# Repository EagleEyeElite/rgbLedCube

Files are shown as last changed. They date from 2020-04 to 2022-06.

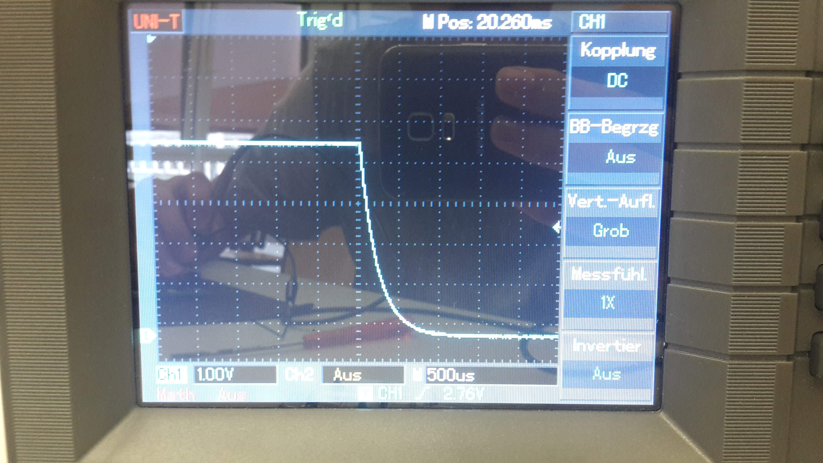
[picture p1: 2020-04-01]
board/notes/20180619_152910.jpg

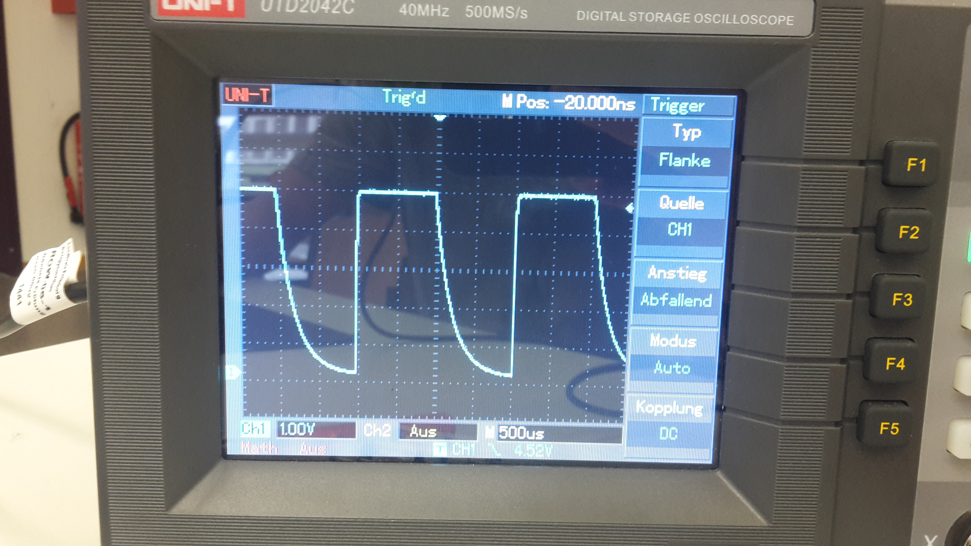
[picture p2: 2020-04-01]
board/notes/20180619_154544.jpg

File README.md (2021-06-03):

# 3x3x3 RGB LED Cube

## video
Led Cube (https://www.youtube.com/watch?v=q-ZB6mgsY2I "LED Cube") \
click image to open video

## board git conf:
[git setup](https://jnavila.github.io/plotkicadsch/) \
[example](https://github.com/John-Nagle/ttyloopdriver)

## programmer examples
```
Arduino: get terminal: avrdude -c stk500v1 -b 19200 -P /dev/ttyACM0 -p atmega1284p -t
Programmer: avrdude -c stk500 -b 115200 -P /dev/ttyACM0 -p atmega1284p -t
get all available ports: ls -l /dev/ttyACM*
```

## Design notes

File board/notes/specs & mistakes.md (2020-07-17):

Specs:
- mosfet: needs 1ms to turn off (from 5V to 0) (no load), switches back on instantly (no load)
 - but: switches instantly off aswell once there is a load -> no ghosting
- all TLC data lines switch instantly, only very small impacts on other lines
- 5V: on last TLC 5V pin, 0.25V ripple -> 5% power ripple, great for TLC
- no ripple on GND pin

Blank (on TLC) 1µS to switch on, switches off immediately
   -> (on µ-C) 1µS to switch off, switches on immediately
   -> delay due transistor inversion
   -> options: remove/short transitor, mosfets provide enough protection
	-replace R2 with 1k

mistakes:
    - TLC blank inverter (obsulete)
    - no debounce capazitor for switches
    - log instead of linear pot
    - too big capacitors (1000µF)
    - 22pf capacitor for 20 mhz crystal seems to break it
    - no usart serial port for debugging
    - n-channel mosfet would be better
    - no readout for TLC error register (useful for debugging)
    - dedicated reset button, button that triggers software reset would be better

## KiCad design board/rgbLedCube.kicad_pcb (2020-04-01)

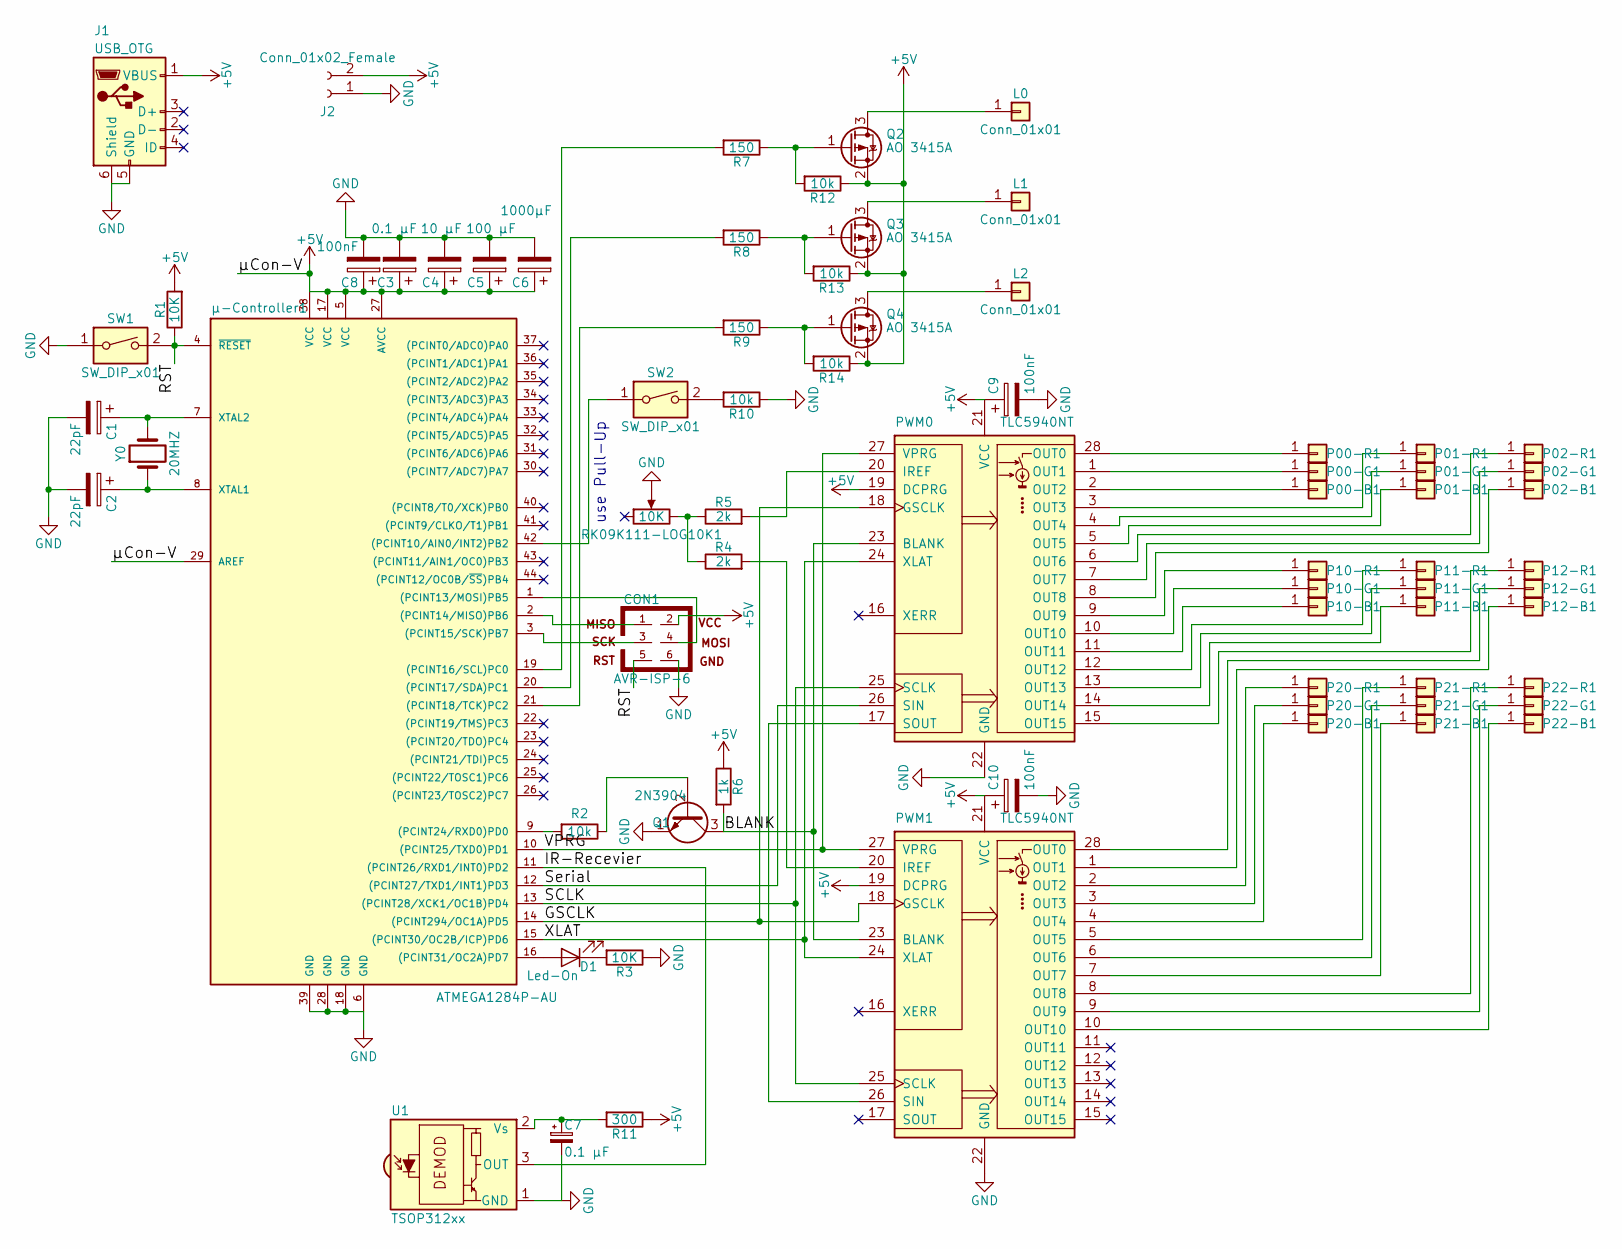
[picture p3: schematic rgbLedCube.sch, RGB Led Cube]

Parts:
C1, C2: 22pF; C_0603_HandSoldering
C3, C7: 0.1 µF; C_0603_HandSoldering
C4: 10 µF; CP_Elec_5x5.3
C5: 100 µF; CP_Elec_5x5.8
C6: 1000µF; CP_Elec_10x10.5
C8, C9, C10: 100nF; C_0603_HandSoldering
CON1: AVR-ISP-6; Pin_Header_Angled_2x03_Pitch2.54mm
D1: Led-On; LED_0603_HandSoldering
J1: USB_OTG; USB_Micro_Conn_Reichelt_Version_2
J2: Conn_01x02_Female; Pin_Header_Angled_1x02_Pitch2.54mm
L0, L1, L2: Conn_01x01; Pin_Header_Straight_1x01_Pitch2.54mm
P00-B1, P00-G1, P00-R1, P01-B1, P01-G1, P01-R1, P02-B1, P02-G1, P02-R1, P10-B1, P10-G1, P10-R1, P11-B1, P11-G1, P11-R1, P12-B1, P12-G1, P12-R1, P20-B1, P20-G1, P20-R1, P21-B1, P21-G1, P21-R1, P22-B1, P22-G1, P22-R1: Conn_01x01; Pin_Header_Straight_1x01_Pitch2.54mm
PWM0, PWM1: TLC5940NT; DIP-28_W7.62mm
Q1: 2N3904; TO-92_Molded_Narrow
Q2, Q3, Q4: AO 3415A; SOT-23
R1, R3: 10K; R_0805_HandSoldering
R2, R10, R12, R13, R14: 10k; R_0805_HandSoldering
R4, R5: 2k; R_0805_HandSoldering
R6: 1k; R_0805_HandSoldering
R7, R8, R9: 150; R_0805_HandSoldering
R11: 300; R_0805_HandSoldering
RK09K111-LOG10K1: 10K; Potentiometer-Alps
SW1, SW2: SW_DIP_x01; SW_Tactile_SPST_Angled_PTS645Vx83-2LFS
U1: TSOP312xx; IRReceiver_Vishay_CAST-3pin
Y0: 20MHZ; Crystal_SMD_HC49-SD
µ-Controller1: ATMEGA1284P-AU; TQFP-44_10x10mm_Pitch0.8mm

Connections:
+5V: C3.1, C4.1, C5.1, C6.1, C8.1, C9.1, C10.1, CON1.2, J1.1 (VBUS), J2.2, PWM0.19 (DCPRG), PWM0.21 (VCC), PWM1.19 (DCPRG), PWM1.21 (VCC), Q2.2 (S), Q3.2 (S), Q4.2 (S), R1.2, R6.1, R11.1, R12.1, R13.1, R14.1, µ-Controller1.5 (VCC), µ-Controller1.17 (VCC), µ-Controller1.27 (AVCC), µ-Controller1.29 (AREF), µ-Controller1.38 (VCC)
/BLANK: PWM0.23 (BLANK), PWM1.23 (BLANK), Q1.3 (C), R6.2
/GSCLK: PWM0.18 (GSCLK), PWM1.18 (GSCLK), µ-Controller1.14 ((PCINT294/OC1A)PD5)
/IR-Recevier: U1.3 (OUT), µ-Controller1.11 ((PCINT26/RXD1/INT0)PD2)
/RST: CON1.5, R1.1, SW1.2, µ-Controller1.4 (~RESET)
/SCLK: PWM0.25 (SCLK), PWM1.25 (SCLK), µ-Controller1.13 ((PCINT28/XCK1/OC1B)PD4)
/Serial: PWM0.26 (SIN), µ-Controller1.12 ((PCINT27/TXD1/INT1)PD3)
/VPRG: PWM0.27 (VPRG), PWM1.27 (VPRG), µ-Controller1.10 ((PCINT25/TXD0)PD1)
/XLAT: PWM0.24 (XLAT), PWM1.24 (XLAT), µ-Controller1.15 ((PCINT30/OC2B/ICP)PD6)
GND: C1.2, C2.2, C3.2, C4.2, C5.2, C6.2, C7.2, C8.2, C9.2, C10.2, CON1.6, J1.5 (GND), J1.6 (Shield), J2.1, PWM0.22 (GND), PWM1.22 (GND), Q1.1 (E), R3.1, R10.1, RK09K111-LOG10K1.2, SW1.1, U1.1 (GND), µ-Controller1.6 (GND), µ-Controller1.18 (GND), µ-Controller1.28 (GND), µ-Controller1.39 (GND)
unnamed: C1.1, Y0.2, µ-Controller1.7 (XTAL2)
unnamed: C2.1, Y0.1, µ-Controller1.8 (XTAL1)
unnamed: C7.1, R11.2, U1.2 (Vs)
unnamed: CON1.1, µ-Controller1.2 ((PCINT14/MISO)PB6)
unnamed: CON1.3, µ-Controller1.3 ((PCINT15/SCK)PB7)
unnamed: CON1.4, µ-Controller1.1 ((PCINT13/MOSI)PB5)
unnamed: D1.1 (K), R3.2
unnamed: D1.2 (A), µ-Controller1.16 ((PCINT31/OC2A)PD7)
unnamed: L0.1, Q2.3 (D)
unnamed: L1.1, Q3.3 (D)
unnamed: L2.1, Q4.3 (D)
unnamed: P00-B1.1, PWM0.2 (OUT2)
unnamed: P00-G1.1, PWM0.1 (OUT1)
unnamed: P00-R1.1, PWM0.28 (OUT0)
unnamed: P01-B1.1, PWM0.5 (OUT5)
unnamed: P01-G1.1, PWM0.4 (OUT4)
unnamed: P01-R1.1, PWM0.3 (OUT3)
unnamed: P02-B1.1, PWM0.8 (OUT8)
unnamed: P02-G1.1, PWM0.7 (OUT7)
unnamed: P02-R1.1, PWM0.6 (OUT6)
unnamed: P10-B1.1, PWM0.11 (OUT11)
unnamed: P10-G1.1, PWM0.10 (OUT10)
unnamed: P10-R1.1, PWM0.9 (OUT9)
unnamed: P11-B1.1, PWM0.14 (OUT14)
unnamed: P11-G1.1, PWM0.13 (OUT13)
unnamed: P11-R1.1, PWM0.12 (OUT12)
unnamed: P12-B1.1, PWM1.1 (OUT1)
unnamed: P12-G1.1, PWM1.28 (OUT0)
unnamed: P12-R1.1, PWM0.15 (OUT15)
unnamed: P20-B1.1, PWM1.4 (OUT4)
unnamed: P20-G1.1, PWM1.3 (OUT3)
unnamed: P20-R1.1, PWM1.2 (OUT2)
unnamed: P21-B1.1, PWM1.7 (OUT7)
unnamed: P21-G1.1, PWM1.6 (OUT6)
unnamed: P21-R1.1, PWM1.5 (OUT5)
unnamed: P22-B1.1, PWM1.10 (OUT10)
unnamed: P22-G1.1, PWM1.9 (OUT9)
unnamed: P22-R1.1, PWM1.8 (OUT8)
unnamed: PWM0.17 (SOUT), PWM1.26 (SIN)
unnamed: PWM0.20 (IREF), R5.2
unnamed: PWM1.20 (IREF), R4.2
unnamed: Q1.2 (B), R2.1
unnamed: Q2.1 (G), R7.1, R12.2
unnamed: Q3.1 (G), R8.1, R13.2
unnamed: Q4.1 (G), R9.1, R14.2
unnamed: R2.2, µ-Controller1.9 ((PCINT24/RXD0)PD0)
unnamed: R4.1, R5.1, RK09K111-LOG10K1.3
unnamed: R7.2, µ-Controller1.19 ((PCINT16/SCL)PC0)
unnamed: R8.2, µ-Controller1.20 ((PCINT17/SDA)PC1)
unnamed: R9.2, µ-Controller1.21 ((PCINT18/TCK)PC2)
unnamed: R10.2, SW2.2
unnamed: SW2.1, µ-Controller1.42 ((PCINT10/AIN0/INT2)PB2)

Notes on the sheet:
use Pull-Up

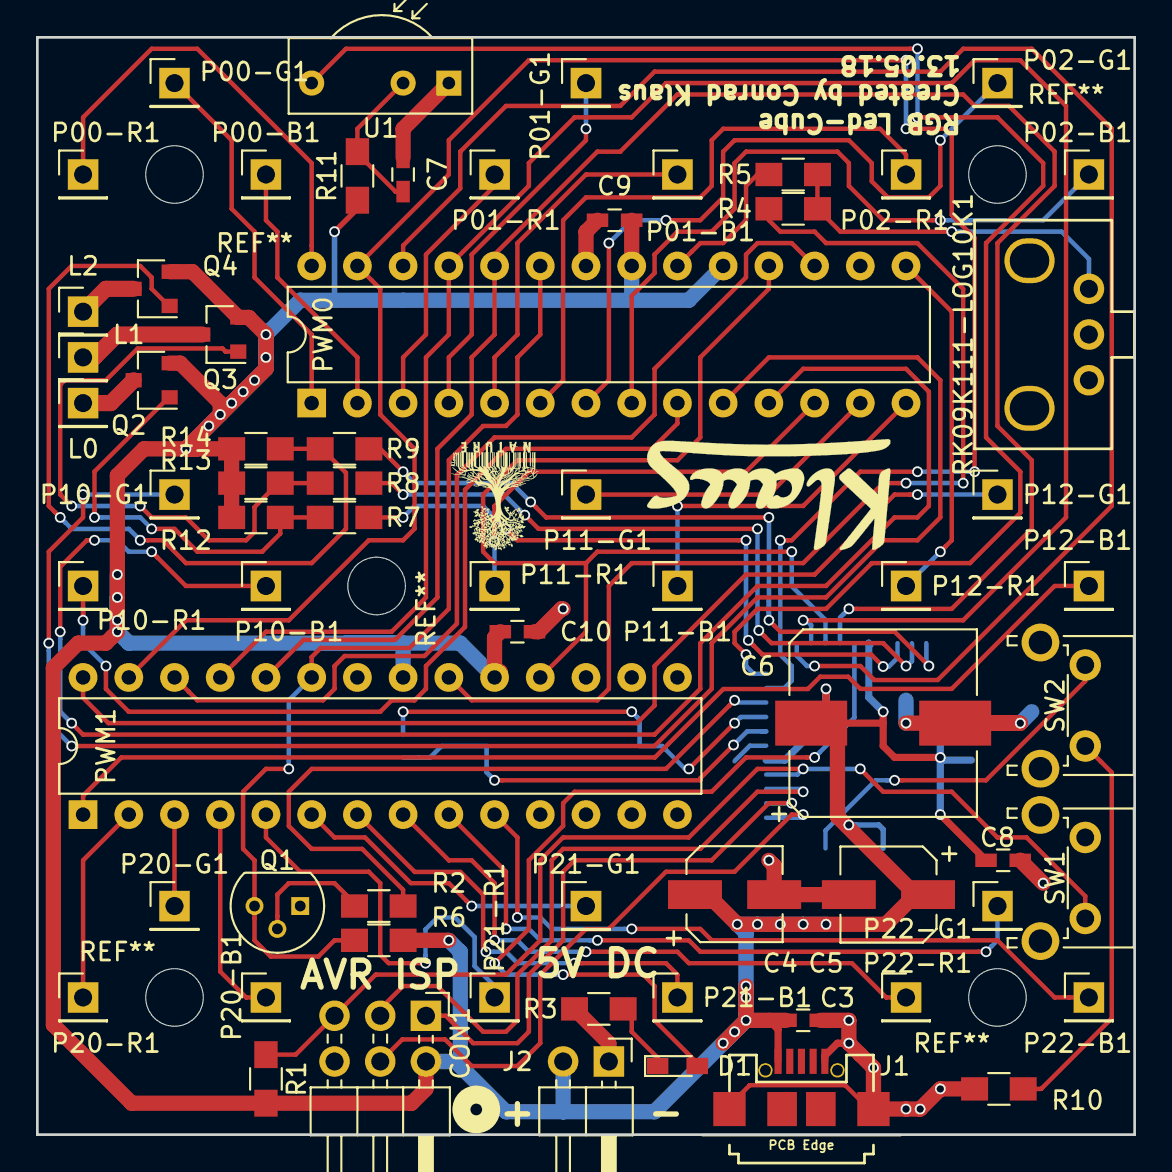
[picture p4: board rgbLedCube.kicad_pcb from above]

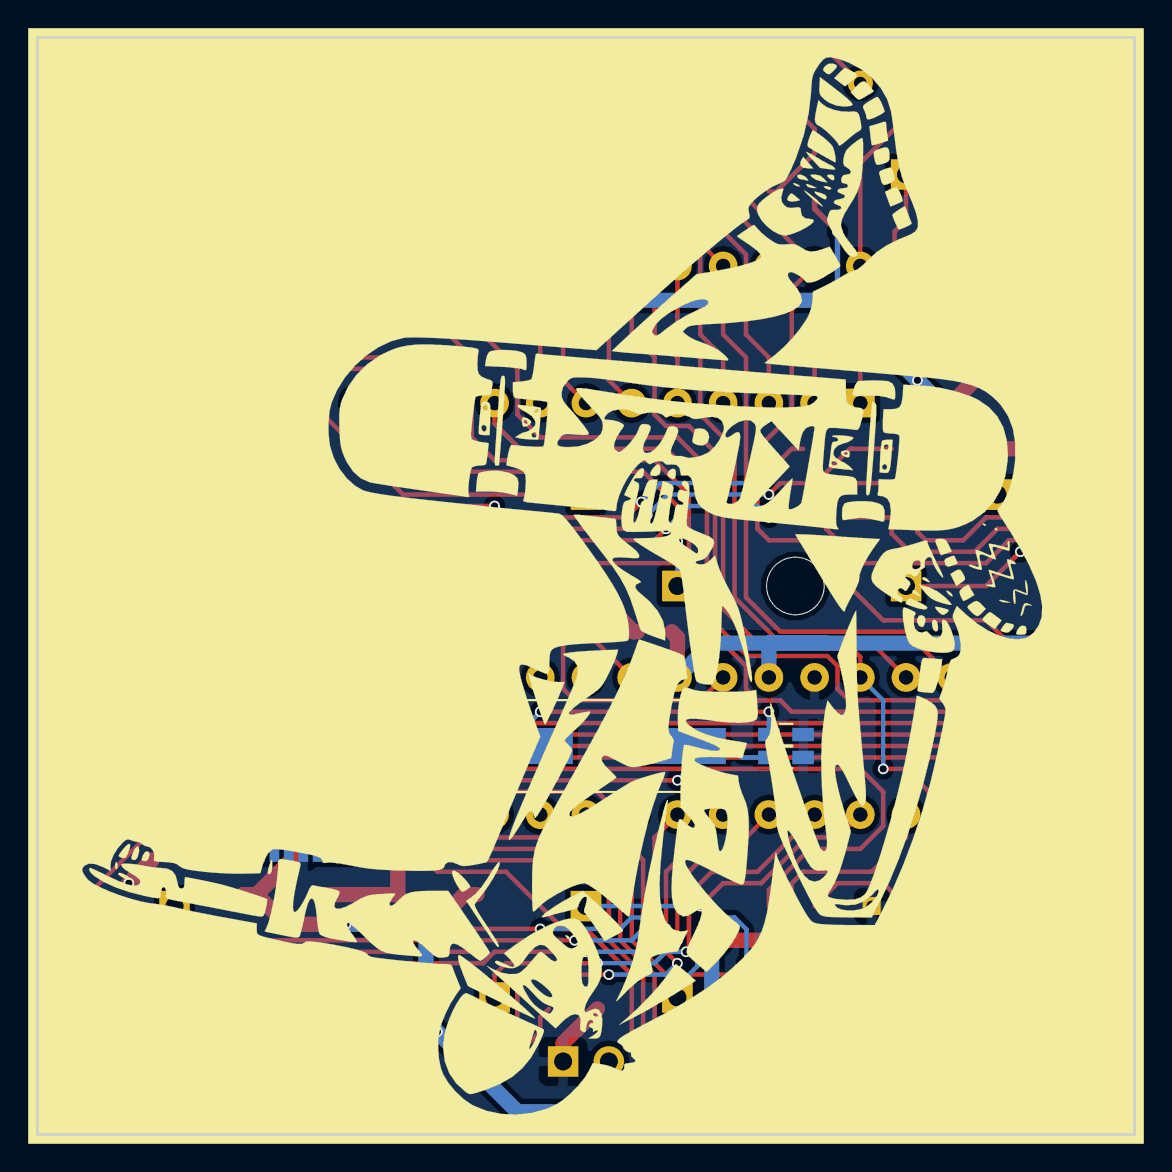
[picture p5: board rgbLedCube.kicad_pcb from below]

Board: 2 copper layers, 61.0 x 61.0 mm, 70 parts (4 on the bottom side), 62 nets.

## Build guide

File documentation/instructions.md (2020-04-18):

led panel:
https://www.youtube.com/watch?v=6TpQfvCegF8

also: to stop a led from lighing also the led above, i used black paint at the bottom of the led

my mistakes:
- I tested the leds just with 3V / multimeter without checking volt threspoint
- didnt test with tlc controller, some leds dont light up.

Fix broken Leds:
Issues:
	-When powered with 3 or more Volts led Turns on
	-Multimeter shows ~60 Ohms accross in both directions
	-Forword drop Voltage is 1.1V
	-TLC cant turn it on or only at higher current
-Fix: (exact reason unkown):
	-Warning: once TLC can already turn LED at high current on, its very close to break the Led
	-if the Led is at 3/5V on, but dimmer than other Leds its broken for good! 

	-put shortly 3V across with instant Voltage drop with current increase, if it doesn't help, go up to 5V
	-check if Issues remain
	-be very carefully once TLC is able to power it a bit, its close to breaking for good!
	-repeat until Ohms go into kilo ohms and forward drop Valage is normle

current PCB has some flaws: checkout board/notes/specs & mistakes.md

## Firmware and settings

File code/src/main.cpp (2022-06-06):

/*
 * main.cpp
 *
 * Created: 21.08.2018 09:43:03
 * Author : Conrad
 */

#include "hardware/hardware.h"
#include "animations/animations.h"
#include "test/interfaceTest.h"

int main() {
    initHardware();

    // benchmark(testBenchmarkSpeed, 1);
    // testAll();
    // basic();

    runAnimations();    // while loop
}

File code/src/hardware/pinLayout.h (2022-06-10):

//
// Created by Conrad Klaus on 06.06.22.
//

#pragma once

#define SW 2    // PB2 - switch

#define Layer0 0    // PC0 - mosfet for led layer
#define Layer1 1    // PC1
#define Layer2 2    // PC2

#define BLANK 0 // PD0 - when low, it's high on the pcb and disables the tlc output
#define VPRG 1  // PD1 - sets grayscale / dot correction (dc) mode
#define IR_Rec 2    // PD2
#define SIN 3   // PD3 - serial in
#define SCLK 4  // PD4 - serial clock
#define GSCLK 5 // PD5	//OC1A - grayscale clock
#define XLAT 6  // PD6 - latches serial data into registers
#define LED 7   // PD7

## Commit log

2020-04-18 add Led Fix
2020-07-17 add LED Tester
2020-07-17 add DC Control for LED check
2021-06-03 include demo video in led cube
2022-04-06 fix: return to sleep after interrupt
2022-06-04 add software reset and fix USART interrupt
2022-06-06 minimize eeprom writes
    - writes only occur after hardware resets
    - add config to disable eeprom writes
    - refactor, split led driver code into sub files
    [Frame.cpp]
2022-06-10 fix: blue flashing LED in display
    - remove shared state
    - functional uart transmission
    - cleanup
    [Frame.cpp]
2022-06-10 improve button reliability
